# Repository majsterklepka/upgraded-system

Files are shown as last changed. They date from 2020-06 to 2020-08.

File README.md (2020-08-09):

# upgraded-system
Arduino Based Multi-channel Voltmeter

Arduino Design, multi-channel ADC.

- Application for OS Linux, works in terminal mode
- Sketch for Arduino UNO
- hardware project of shield for Arduino Uno

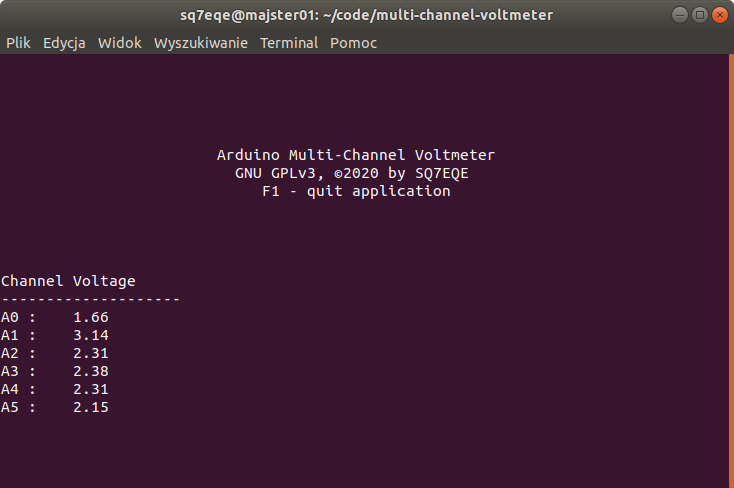
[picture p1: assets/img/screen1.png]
screen1


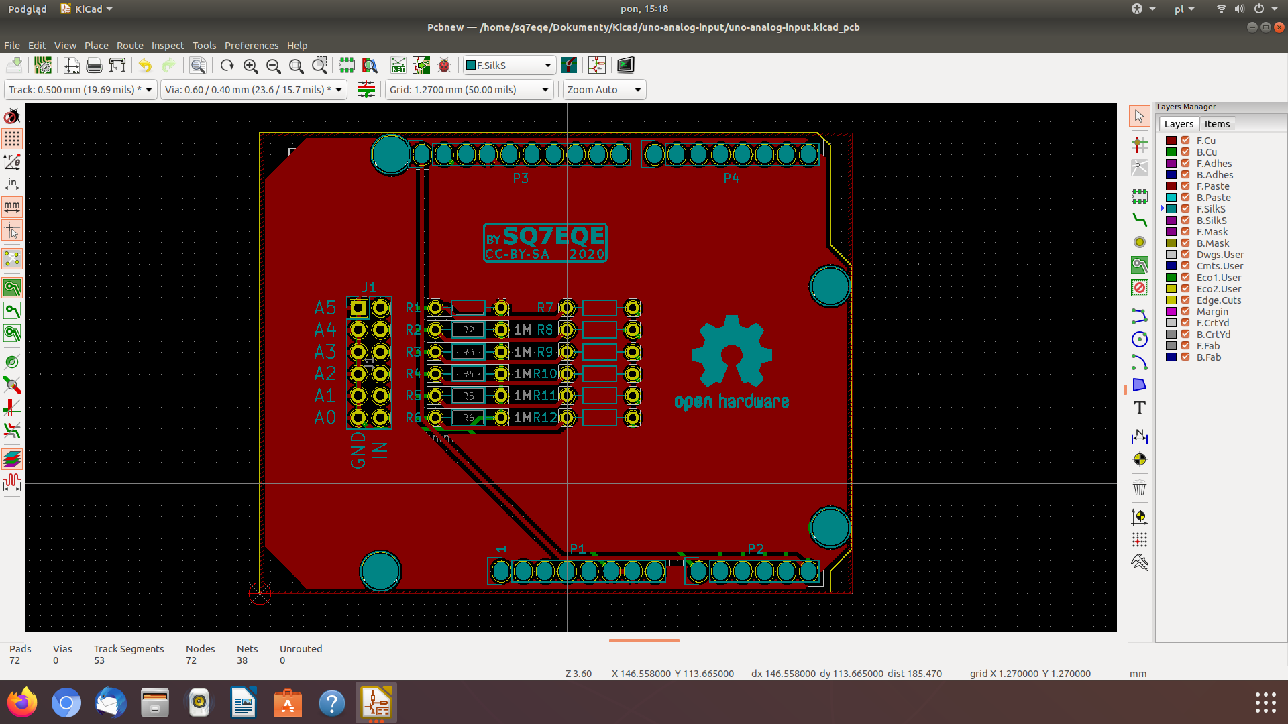
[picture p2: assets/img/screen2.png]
screen2


That's All! Have a fun!

## Credits

All contents on this repo is published under terms of: [CC-BY-SA](https://creativecommons.org/licenses/by-sa/4.0/) for hardware & [GNU GPLv3](https://www.gnu.org/licenses/gpl-3.0.html) for Linux software

_MSc Paweł Sobótka (SQ7EQE)_

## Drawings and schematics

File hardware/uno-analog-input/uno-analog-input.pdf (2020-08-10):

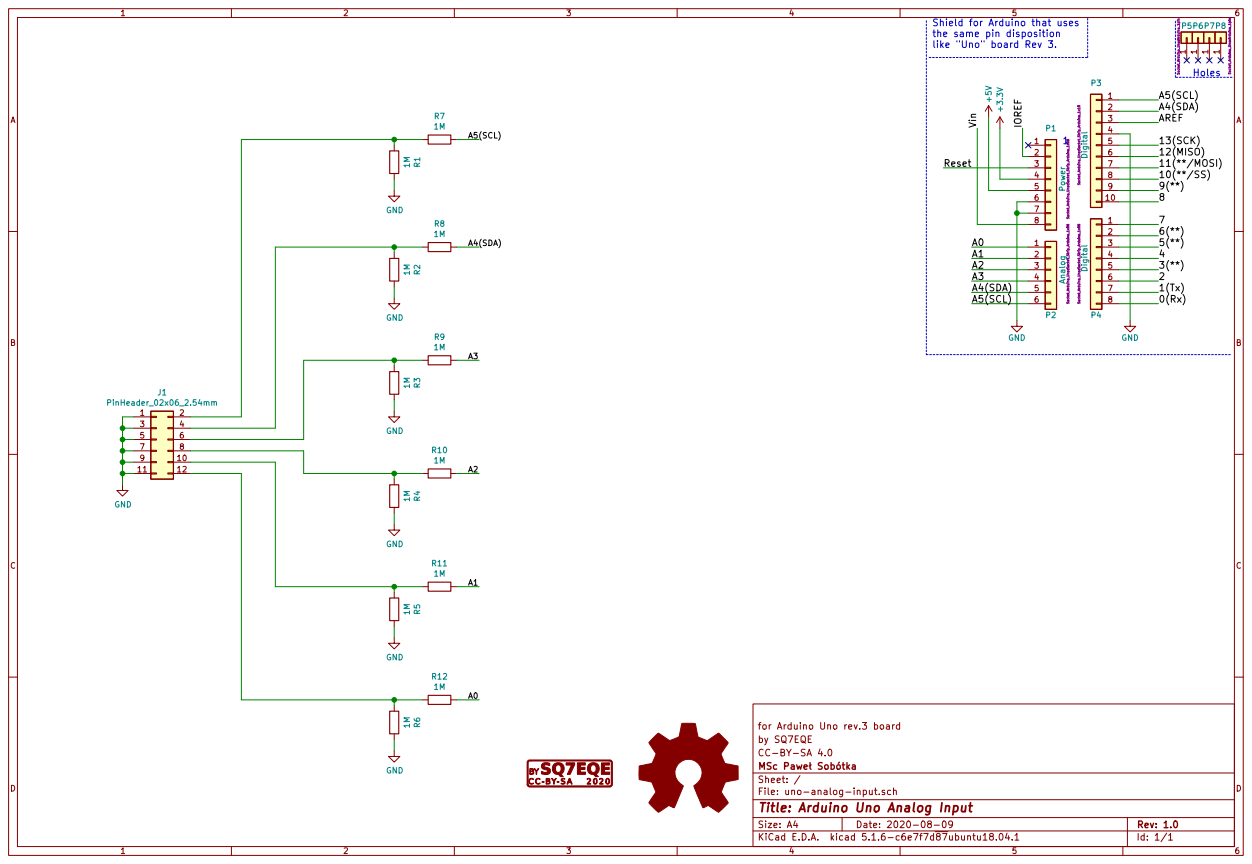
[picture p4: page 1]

the same pin disposition

J1 PinHeader_02x06_2.54mm
for Arduino Uno rev.3 board 1

by SQ7EQE
File: uno-analog-input.sch Sheet: / MSc Pawe Sobótka CC-BY-SA 4.0

Id: 1/1 Title: Arduino Uno Analog Input

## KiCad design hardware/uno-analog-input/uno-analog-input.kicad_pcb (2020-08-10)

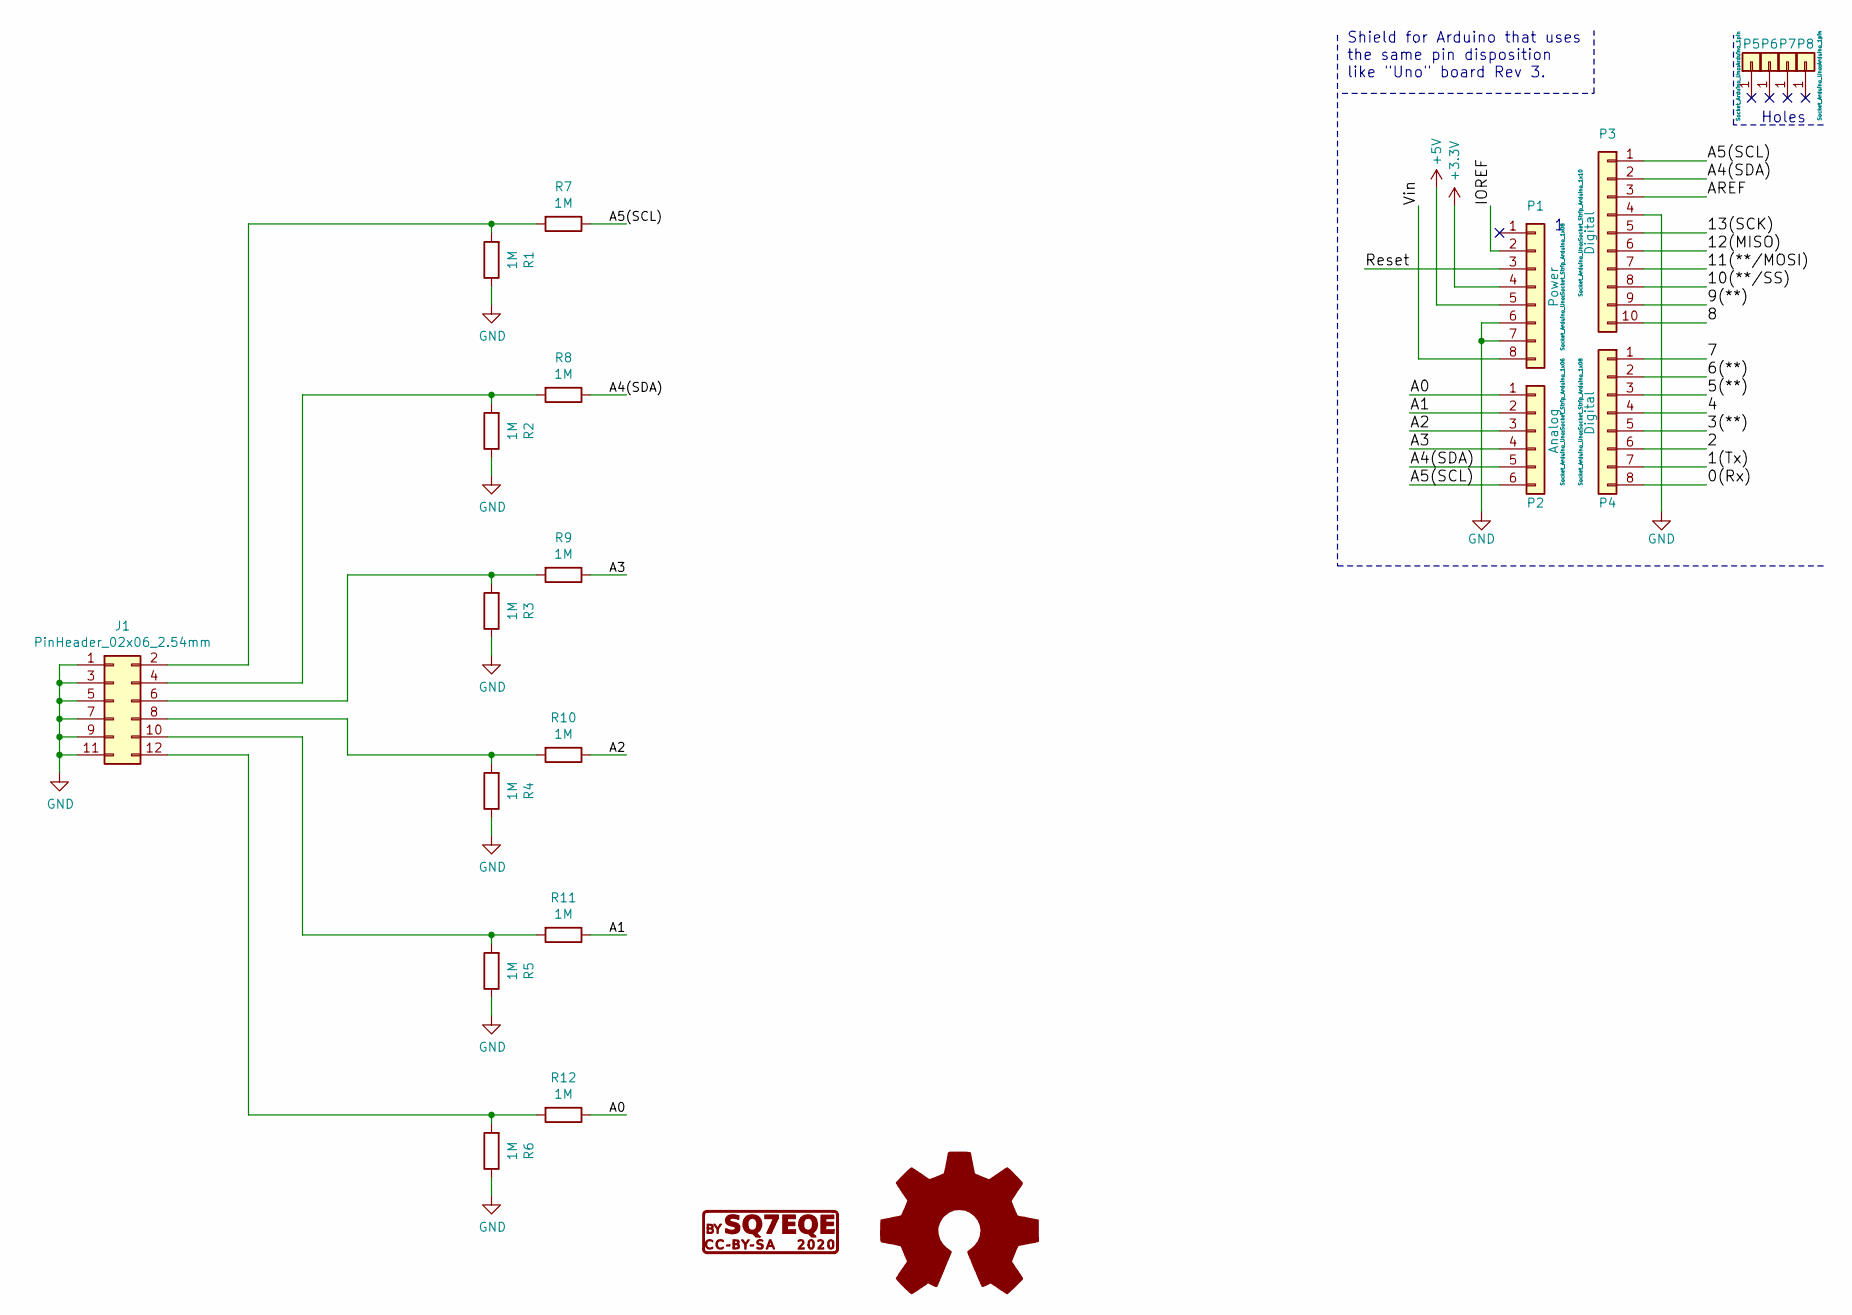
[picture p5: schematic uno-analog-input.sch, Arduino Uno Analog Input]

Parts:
G1: CC-BY-SA; cc-by-sa
G2: Logo_Open_Hardware_Large; OSHW-Logo2_14.6x12mm_SilkScreen
J1: PinHeader_02x06_2.54mm; PinHeader_2x06_P2.54mm_Vertical
P1: Power; Socket_Strip_Arduino_1x08
P2: Analog; Socket_Strip_Arduino_1x06
P3: Digital; Socket_Strip_Arduino_1x10
P4: Digital; Socket_Strip_Arduino_1x08
P5, P6, P7, P8: CONN_01X01; Arduino_1pin
R1, R2, R3, R4, R5, R6, R7, R8, R9, R10, R11, R12: 1M; R_Axial_DIN0204_L3.6mm_D1.6mm_P7.62mm_Horizontal

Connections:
+3V3: P1.4
+5V: P1.5
/0(Rx): P4.8
/1(Tx): P4.7
/2: P4.6
/3(**): P4.5
/4: P4.4
/5(**): P4.3
/6(**): P4.2
/7: P4.1
/8: P3.10
/9(**): P3.9
/10(**/SS): P3.8
/11(**/MOSI): P3.7
/12(MISO): P3.6
/13(SCK): P3.5
/A0: P2.1, R12.1
/A1: P2.2, R11.1
/A2: P2.3, R10.1
/A3: P2.4, R9.1
/A4(SDA): P2.5, P3.2, R8.1
/A5(SCL): P2.6, P3.1, R7.1
/AREF: P3.3
/IOREF: P1.2
/Reset: P1.3
/Vin: P1.8
GND: J1.1, J1.3, J1.5, J1.7, J1.9, J1.11, P1.6, P1.7, P3.4, R1.1, R2.1, R3.1, R4.1, R5.1, R6.1
unnamed: J1.2, R1.2, R7.2
unnamed: J1.4, R2.2, R8.2
unnamed: J1.6, R3.2, R9.2
unnamed: J1.8, R4.2, R10.2
unnamed: J1.10, R5.2, R11.2
unnamed: J1.12, R6.2, R12.2

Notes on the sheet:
Holes
Shield for Arduino that uses the same pin disposition like "Uno" board Rev 3.

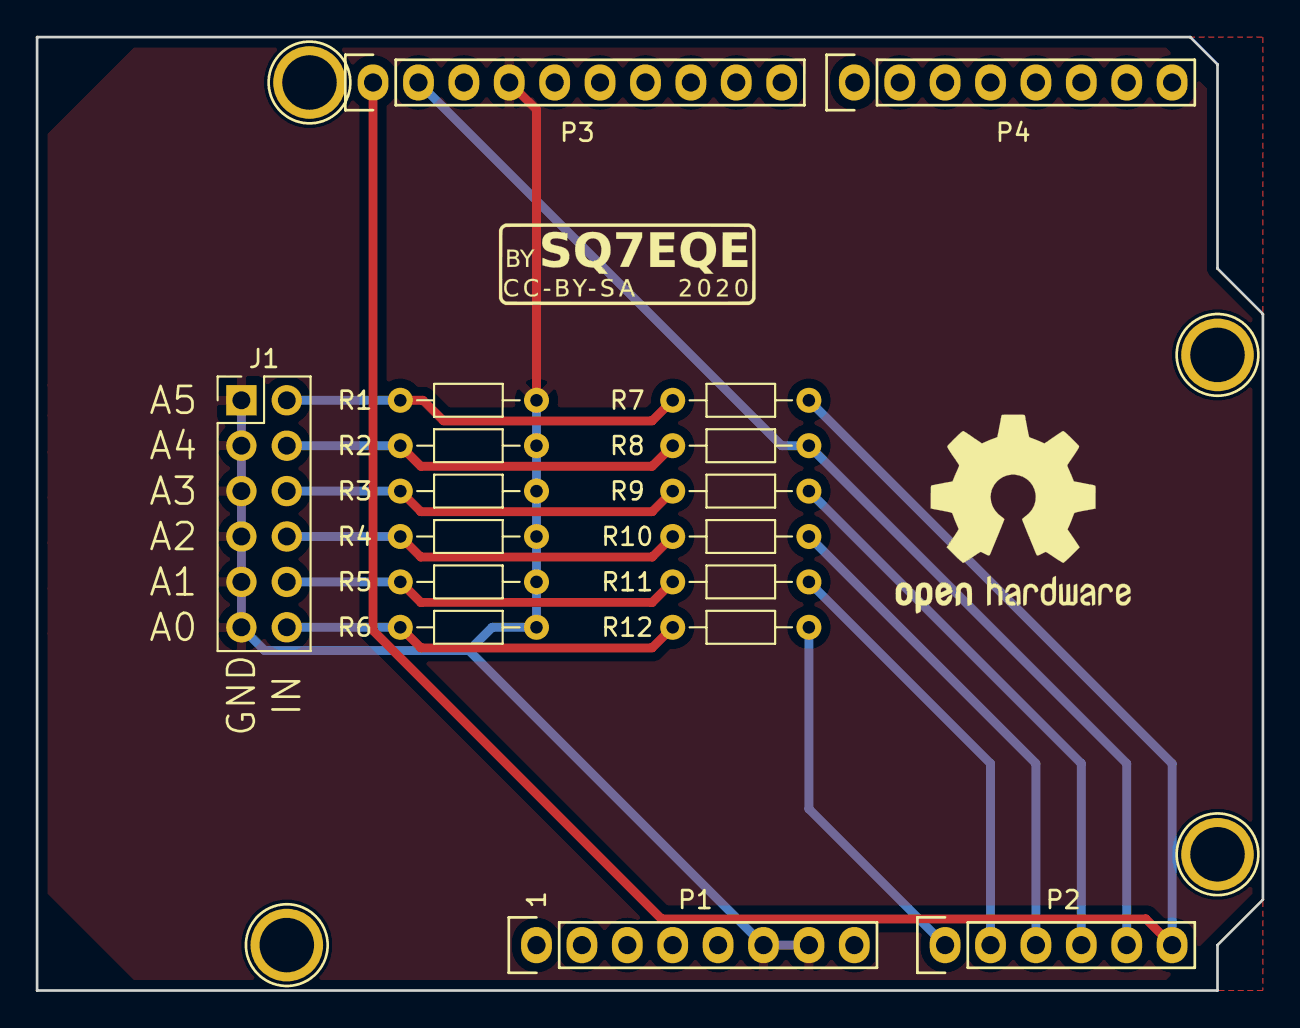
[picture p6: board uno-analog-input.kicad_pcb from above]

Board: 2 copper layers, 68.6 x 53.3 mm, 23 parts (0 on the bottom side), 13 nets.

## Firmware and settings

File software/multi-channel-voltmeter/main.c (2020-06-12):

/*
 * @file main.c
 *
 * @author Paweł Sobótka
 * @date 2020-06-12
 * @license GNU GPLv3
 *
 */


#include <ncurses.h>
#include <pthread.h>
#include <unistd.h>
#include <string.h>
#include "serial.h"
#include "dest.h"

char buff[255];
int frozen;

void frozen0()
{
    if (frozen == 0)
        frozen = 1;
    else
        frozen = 0;
}

int display_data (WINDOW *win, void *data)
{
    if(frozen)
    {
        addstr("frozen ... for 8s");
        refresh();
        sleep(8);
        frozen = 0;
        move(0,0);
        clrtoeol();
        refresh();
    }
    if (data != NULL)
    {
        switch(prefix((const char*)data))
        {
        case 0:
            wmove(win,2,6);
            clrtoeol();
            wprintw(win, "\t%0.2f", suffix((const char*)data));
            break;
        case 1:
            wmove(win,3,6);
            clrtoeol();
            wprintw(win, "\t%0.2f", suffix((const char*)data));
            break;
        case 2:
            wmove(win,4,6);
            clrtoeol();
            wprintw(win, "\t%0.2f", suffix((const char*)data));
            break;
        case 3:
            wmove(win,5,6);
            clrtoeol();
            wprintw(win, "\t%0.2f", suffix((const char*)data));
            break;
        case 4:
            wmove(win,6,6);
            clrtoeol();
            wprintw(win, "\t%0.2f", suffix((const char*)data));
            break;
        case 5:
            wmove(win,7,6);
            clrtoeol();
            wprintw(win, "\t%0.2f", suffix((const char*)data));
            break;
        default:
            endwin();
            return 0;
        }
    }
    wrefresh(win);
    return 0;
}
void* thread_win0(void* data)
{
    WINDOW *win = (WINDOW*)data;
    while ( 1 )
    {
        use_window(win,display_data,buff);
        usleep(5000);
    }
    pthread_exit(NULL);
}

WINDOW *win01, *win02;

int main()
{
    int ch,k;
    int wl1,wc1,y1,x1;
    pthread_t t1,t2;
    char mesg[] = "Arduino Multi-Channel Voltmeter";
    char mesg1[] = "GNU GPLv3, ©2020 by SQ7EQE";
    char mesg2[] = "F1 - quit application";
    frozen = 0;

    initscr();
    keypad(stdscr, TRUE);
    wl1 = LINES/2;
    wc1 = COLS;
    raw();
    noecho();
    refresh();
    curs_set(0);

    win01 = newwin(wl1,wc1,0,0);
    win02 = newwin(wl1,wc1,wl1,0);

    scrollok(win02,FALSE);
    scrollok(win01, FALSE);

    getmaxyx(win01,y1,x1);

    mvwprintw(win01, y1/2 - 1, (x1 - strlen(mesg))/2, "%s", mesg);
    mvwprintw(win01, y1/2, (x1 - strlen(mesg1))/2, "%s", mesg1);
    mvwprintw(win01, y1/2 + 1, (x1 - strlen(mesg2))/2, "%s", mesg2);

    wrefresh(win02);

    mvwprintw(win02, 0, 0, "Channel\tVoltage");

    wmove(win02, 1,0);
    whline(win02, '-', 20);

    for (k = 2; k < 8; k++)
    {
        mvwprintw(win02,k,0,"A%d : ", k-2);
    }

    wrefresh(win01);

    pthread_create(&t1,NULL,thread_win0,win02);
    pthread_create(&t2,NULL,serial01,buff);

    while ((ch = getch()) != KEY_F(1))
    {
        switch(ch)
        {
        case 'f':
            frozen0();
            break;
        default:
            break;
        }
        sleep(1);
    }
    endwin();
    return 0;
}

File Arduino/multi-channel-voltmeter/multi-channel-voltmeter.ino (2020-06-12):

/*
 * @file multi-channel-voltmeter.ino
 * 
 * @author Paweł Sobótka
 * @license GNU GPLv3
 * @date 2020-06-11
 * 
 */

 int analogIN[]= {A0, A1, A2, A3, A4, A5};
 int analogR[6];
 
void setup() {
 Serial.begin(9600);

}

void loop() {

  for (int i = 0; i < 6; i++)
  {
    analogR[i] = analogRead(analogIN[i]);
    delay(10);
   }
   for (int i = 0; i < 6;i++)
   {
    String pref0 = String(0);
    String pref1 = String(i);
    String suff = String(analogR[i]);
    Serial.println(String(pref0 + pref1 + suff));
    delay(40);
   }
   
  delay(50);
   
  }

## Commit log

2020-06-12 update
    change in thread_win0() function from sleep to usleep
    faster refresh data
2020-08-09 new file uploaded
    hardware project for Arduino Multi-Channel Voltmeter
    shield for Arduino Uno
    [uno-analog-input-B_Cu.gbr, uno-analog-input-B_Mask.gbr, uno-analog-input-B_SilkS.gbr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]
2020-08-09 uploaded file
    Screenshoot with pcb design from KiCad
2020-08-10 upload modified file
    [uno-analog-input-B_Cu.gbr, uno-analog-input-B_Mask.gbr, uno-analog-input-B_SilkS.gbr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]
